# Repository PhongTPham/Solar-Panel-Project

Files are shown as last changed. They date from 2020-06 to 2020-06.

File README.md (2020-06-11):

# Introduction
This Solar Panel Project is a class project for a Power Electronics class. The aim was to build a device related to power that can be used for personal use, is relatively inexpensive and simple to assemble.

## [Link to the hardware](https://github.com/PhongTPham/Solar-Panel-Project/wiki/Main-Page#hardware)

This is what the completed circuit looks like:
solarPanelProject

## [Link to the Testing](https://github.com/PhongTPham/Solar-Panel-Project/wiki/Main-Page#testing)

# Current Status of this project:
At the moment this project doesn't quite work. When I was soldering parts onto the PCB something happened that fried my buck booster IC and as a result the entire section after the SPDT switch is rendered unusable since it feeds directly to the buck booster. If I connect my battery straight to the USB port and plug in a charger than it works just fine, but that defeats the purpose of the project.

## [Link to Future Considerations](https://github.com/PhongTPham/Solar-Panel-Project/wiki/Main-Page#future-considerations)

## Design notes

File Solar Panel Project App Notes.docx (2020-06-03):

Phong Pham

ENGR460

Stepping Stone

Application Notes

4/13/20

2.5W 5V/500mA Solar Panel

Acquired

A cheap 2.5W solar array

1N4007-TP Diode

https://www.digikey.com/product-detail/en/micro-commercial-co/1N4007-TP/1N4007-TPMSCT-ND/773694

https://www.mccsemi.com/pdf/Products/1N4001-1N4007(DO-41).pdf

High voltage, high current rated diode. Reverse voltage protection with rating of 1000V. Will prevent large

LM3658SD/NOPB Battery Charger

https://www.digikey.com/product-detail/en/texas-instruments/LM3658SD-NOPB/LM3658SD-NOPBCT-ND/808013

http://www.ti.com/lit/ds/symlink/lm3658.pdf

Lithium battery charger with charge current of 1A and battery pack voltage of 4.2 to 6V. Can safely charge a Li battery from USB power source.

PRT-13851 3.7V Lithium Battery

https://www.digikey.com/product-detail/en/sparkfun-electronics/PRT-13851/1568-1493-ND/6605199

https://cdn.sparkfun.com/datasheets/Prototyping/spe-00-502535-400mah-en-1.0ver.pdf

Will charge this from the solar panel for the USB output.

SN74LVC1G3157DBVR SPDT Switch

https://www.digikey.com/product-detail/en/texas-instruments/SN74LVC1G3157DBVR/296-14908-1-ND/562548

http://www.ti.com/general/docs/suppproductinfo.tsp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

Will make it so the device only charges battery when the solar panel is charging.

Buck Boost Voltage Regulator: RT4812

https://www.digikey.com/product-detail/en/richtek-usa-inc/RT4812GJ8F/1028-1512-1-ND/5640521

https://www.richtek.com/assets/product_file/RT4812/DS4812-07.pdf

Will boost battery 3.7V dc to 5V dc for USB output. Features 96% efficiency, output over voltage protection, and adjustable output voltage from 1.8V to 5.5V. Seems pretty good for this project.

Wireless Charger: Samsung 5V/2A wireless charger

Acquired. Is inefficient but that’s not why I’m choosing the wireless charger anyway.

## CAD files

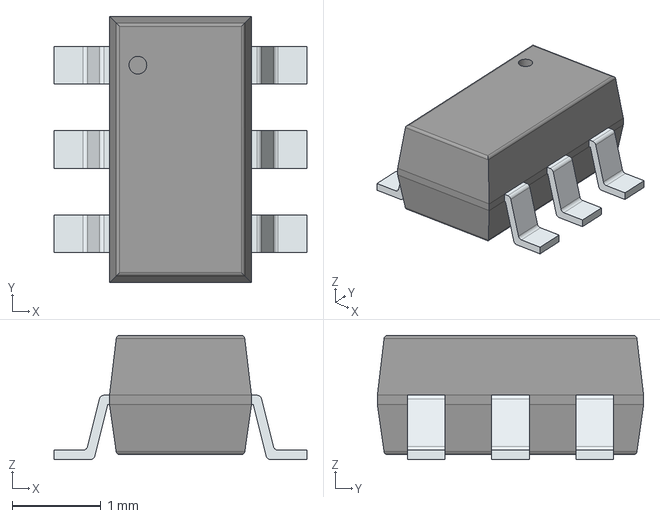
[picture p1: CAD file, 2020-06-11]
Kicad Lib/LIB_DMG6968UDM-7/DMG6968UDM-7/3D/DMG6968UDM-7.stp
2.85 x 3.00 x 1.40 mm
PinsArrayLR

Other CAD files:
Kicad Lib/LIB_DMG6968UDM-7/DMG6968UDM-7/3D/DMG6968UDM-7.stl
Kicad Lib/LIB_DMG6968UDM-7/DMG6968UDM-7/Allegro/sot95p285x140-6n.psm
Kicad Lib/LIB_DMG6968UDM-7/DMG6968UDM-7/DEHDL/dmg6968udm_7/chips/chips.prt

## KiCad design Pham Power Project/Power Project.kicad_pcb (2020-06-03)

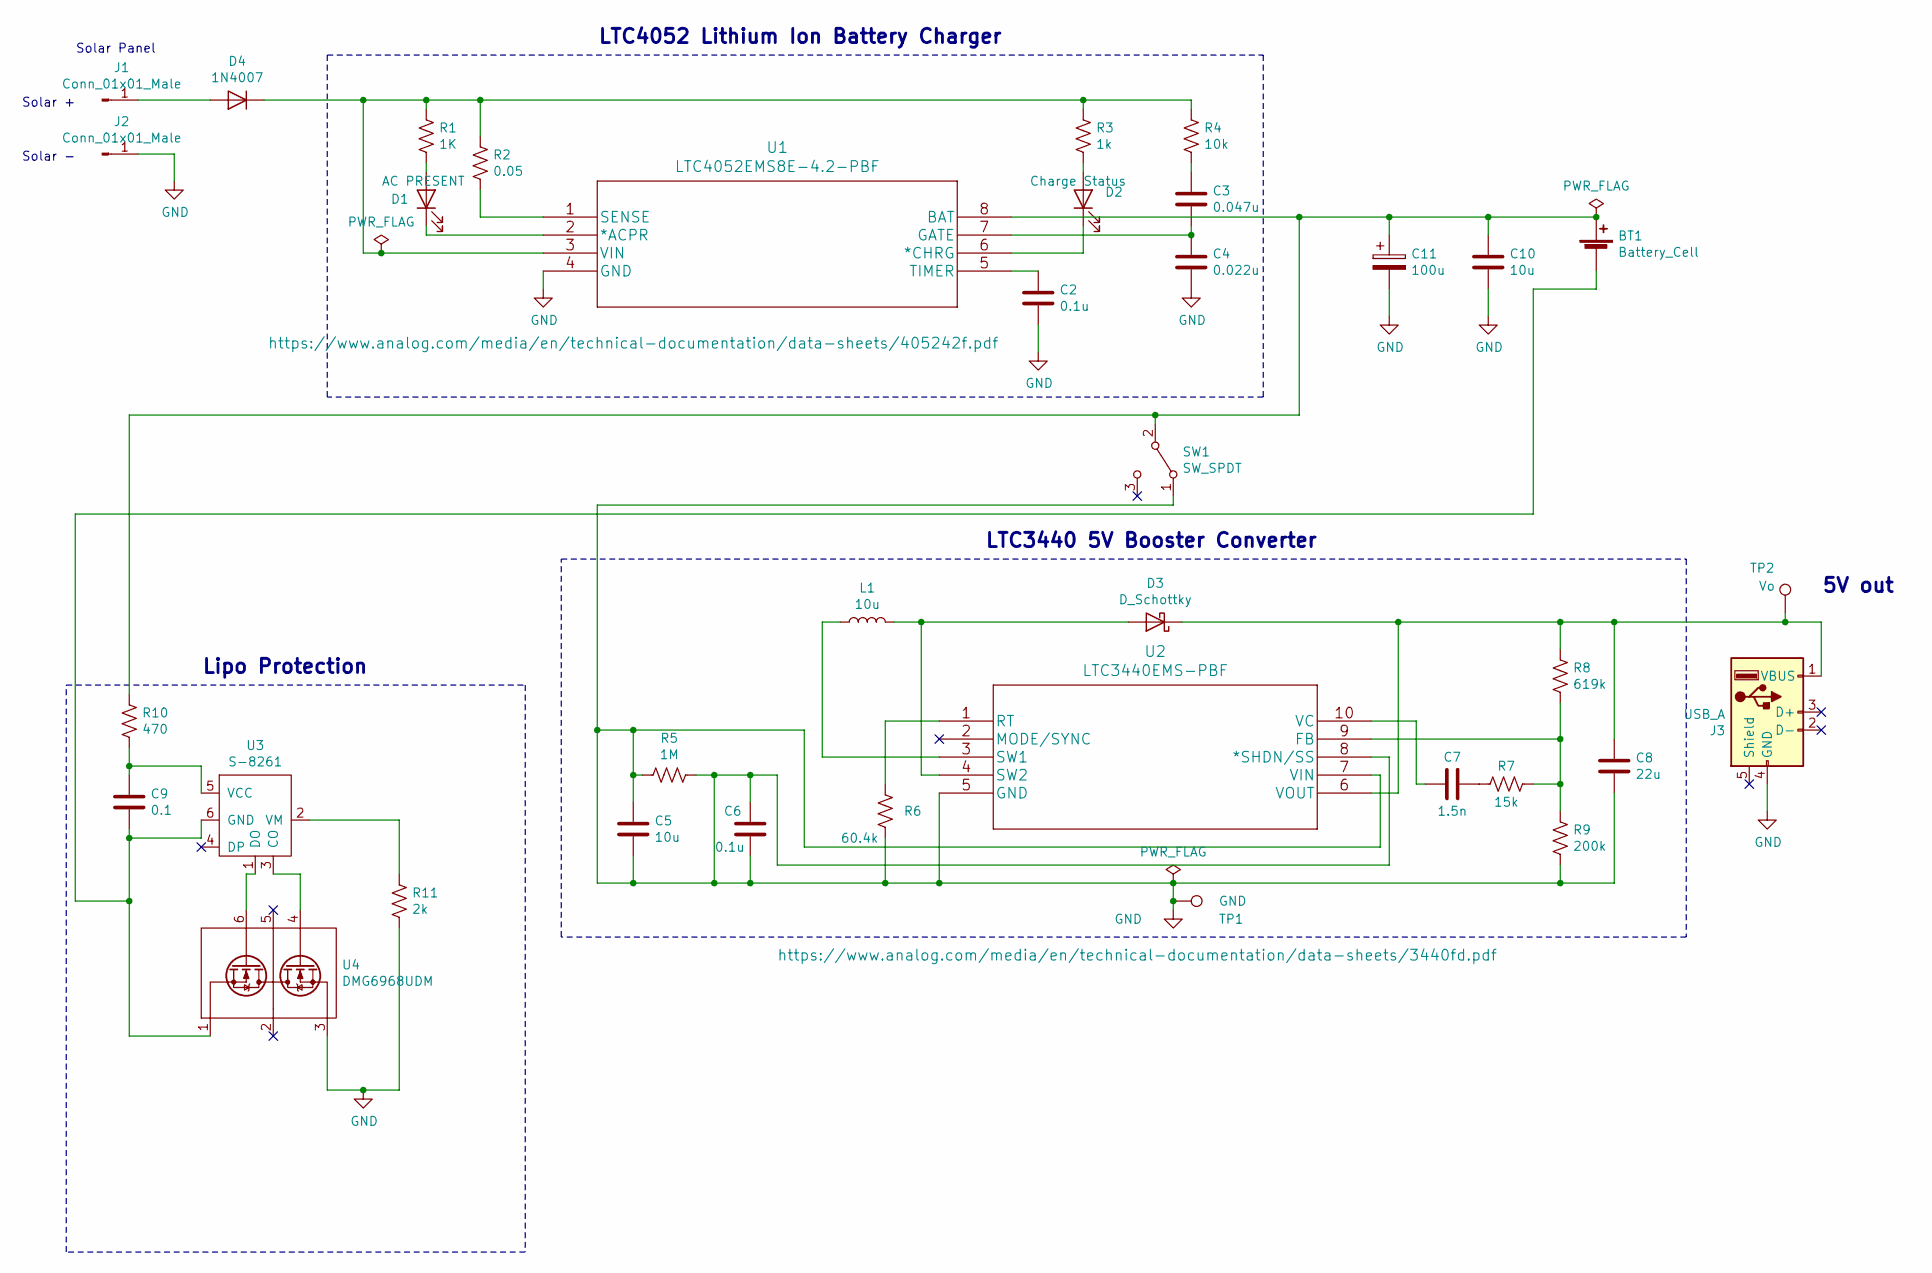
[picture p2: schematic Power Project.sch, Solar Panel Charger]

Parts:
BT1: Battery_Cell; BatteryHolder_MPD_BH-18650-PC2
C2, C6: 0.1u; C_0805_2012Metric
C3: 0.047u; C_0805_2012Metric
C4: 0.022u; C_0805_2012Metric
C5, C10: 10u; C_0805_2012Metric
C7: 1.5n; C_0805_2012Metric
C8: 22u; C_0805_2012Metric
C9: 0.1; C_0805_2012Metric
C11: 100u; CP_Elec_6.3x5.4_Nichicon
D1: AC PRESENT; LED_0805_2012Metric
D2: Charge Status; LED_0805_2012Metric
D3: D_Schottky; D_SMC
D4: 1N4007; D_DO-41_SOD81_P10.16mm_Horizontal
J1, J2: Conn_01x01_Male; SolderWirePad_1x01_Drill0.8mm
J3: USB_A; USB_A_CNCTech_1001-011-01101_Horizontal
L1: 10u; L_0805_2012Metric
R1: 1K; R_0805_2012Metric
R2: 0.05; R_0805_2012Metric
R3: 1k; R_0805_2012Metric
R4: 10k; R_0805_2012Metric
R5: 1M; R_0805_2012Metric
R6: 60.4k; R_0805_2012Metric
R7: 15k; R_0805_2012Metric
R8: 619k; R_0805_2012Metric
R9: 200k; R_0805_2012Metric
R10: 470; R_0805_2012Metric
R11: 2k; R_0805_2012Metric
SW1: SW_SPDT; SW_SPDT_PCM12
TP1: GND; TestPoint_Plated_Hole_D2.0mm
TP2: Vo; TestPoint_Plated_Hole_D2.0mm
U1: LTC4052EMS8E-4.2-PBF
U2: LTC3440EMS-PBF
U3: S-8261; SOT-23-6
U4: DMG6968UDM; SOT-23-6

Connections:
GND: C2.2, C4.2, C5.1, C5.2, C6.1, C6.2, C8.2, C10.2, C11.2, J2.1, J3.4 (GND), R5.1, R5.2, R6.2, R9.2, R11.2, SW1.1 (A), TP1.1, U1.4 (GND), U2.5 (GND), U2.7 (VIN), U2.8 (*SHDN/SS), U4.3
unnamed: BT1.1 (+), C10.1, C11.1, R10.1, SW1.2 (B), U1.8 (BAT)
unnamed: BT1.2 (-), C9.2, U3.6 (GND), U4.1
unnamed: C2.1, U1.5 (TIMER)
unnamed: C3.1, R4.2
unnamed: C3.2, C4.1, U1.7 (GATE)
unnamed: C7.1, R7.2
unnamed: C7.2, U2.10 (VC)
unnamed: C8.1, D3.1 (K), J3.1 (VBUS), R8.1, TP2.1, U2.6 (VOUT)
unnamed: C9.1, R10.2, U3.5 (VCC)
unnamed: D1.1 (K), U1.2 (*ACPR)
unnamed: D1.2 (A), R1.2
unnamed: D2.1 (K), U1.6 (*CHRG)
unnamed: D2.2 (A), R3.2
unnamed: D3.2 (A), L1.2, U2.4 (SW2)
unnamed: D4.1 (K), R1.1, R2.1, R3.1, R4.1, U1.3 (VIN)
unnamed: D4.2 (A), J1.1
unnamed: L1.1, U2.3 (SW1)
unnamed: R2.2, U1.1 (SENSE)
unnamed: R6.1, U2.1 (RT)
unnamed: R7.1, R8.2, R9.1, U2.9 (FB)
unnamed: R11.1, U3.2 (VM)
unnamed: U3.1 (DO), U4.6
unnamed: U3.3 (CO), U4.4

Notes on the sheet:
Solar Panel
Solar +
Solar -
5V out
LTC4052 Lithium Ion Battery Charger
Lipo Protection
LTC3440 5V Booster Converter

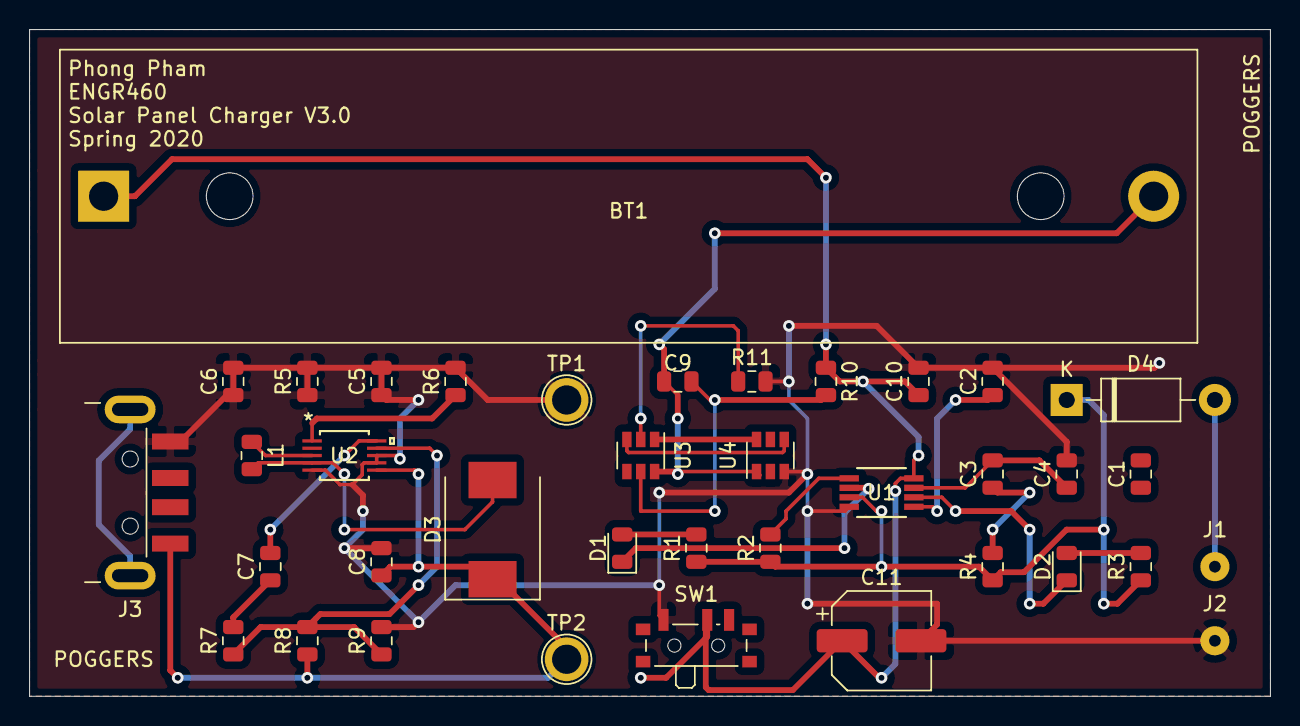
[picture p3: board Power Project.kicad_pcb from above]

Board: 2 copper layers, 85.1 x 45.7 mm, 38 parts (0 on the bottom side), 24 nets.

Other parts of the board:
C1: 1uF; C_0805_2012Metric

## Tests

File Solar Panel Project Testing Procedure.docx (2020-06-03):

Phong Pham

ENGR460

Power Project Stepping Stone 4

May 18, 2020

Project Overview

I will be constructing a wireless charger that uses a 5V Solar Panel and 5V Samsung Wireless charger to charge a lithium-ion battery. The charger will have a 5V booster converter and lip protection built alongside it. These are the 3 main components of the project circuit board:

Lithium Ion Battery Charger

LTC4052EMS8E

The LTC4052 takes the voltage from the solar panel and charges Lipo battery

https://www.analog.com/media/en/technical-documentation/data-sheets/405242f.pdf

5V Booster Converter

LTC3440EMS

LTC3440 converts the 3.7 voltage output of the lipo to 5V for the USB charger.

https://www.analog.com/media/en/technical-documentation/data-sheets/3440fd.pdf

Lipo Protection

S-8261 and DMG6968UDM

The two ICs add additional protection to conditions like overvolt, undervoltage, overcharge and overcurrent.

https://www.ablic.com/en/doc/datasheet/battery_protection/S8261_E.pdf

https://www.diodes.com/assets/Datasheets/ds31758.pdf

Pre-Planning

- Fill out the Academic Exception Form to campus so I can use the project lab to build my board
- Prepare workspace to test board when it is finished being assembled

Initial Procedure

- Confirm all parts have been delivered
- Examine PCB for any faults or defects from shipping or manufacture

Assembly of PCB

- Apply solder paste with stencil
- Pick and place the SMD parts
- Bake the PCB using the project labs oven
- Check ICs after baking in case of shorts or any potential unflowed solder
- Hand Solder through-hole parts
- Check for shorts using multimeter

Testing of the Battery Charger

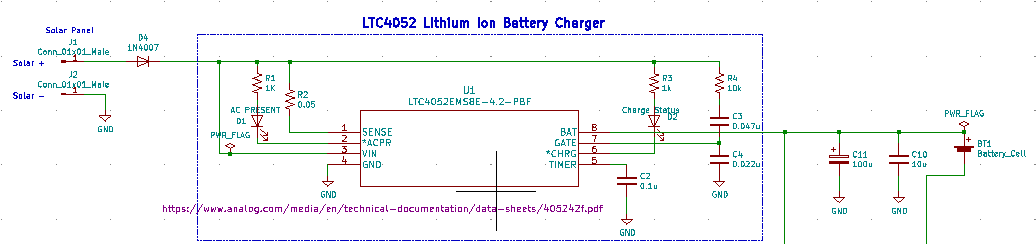
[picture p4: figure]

- Test that the solar panel is able to the charge the battery:
  - D1 and D2 LEDs will indicate that it’s charging
  - D1 (AC present) shows that power is present
  - D2 shows that charging is indeed taking place
- Test the output current: making sure it doesn’t exceed 750mA
- Test the thermal protection that is on the IC: circuit will turn off if the temperature exceeds 140 degrees Celsius.

Testing of the Booster Converter

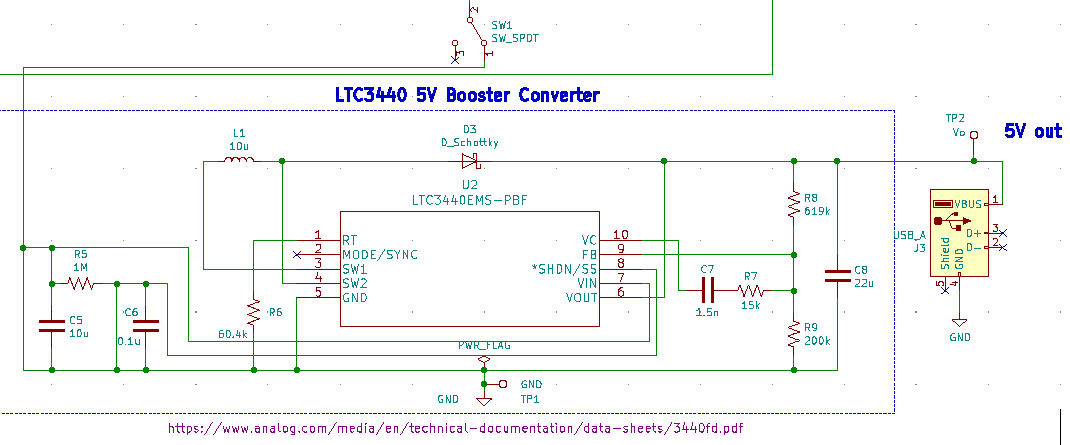
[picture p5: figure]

- We want to verify the 5V output via testing point 2 (TP2)
- Test efficiency using the waveform graphs from Linear Technology

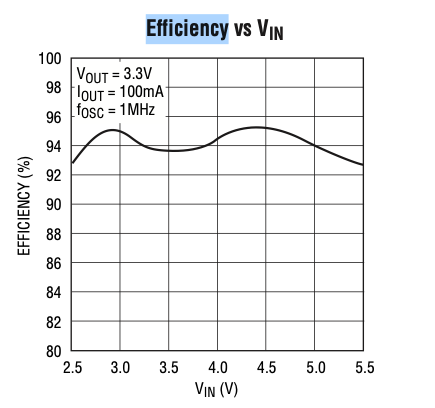
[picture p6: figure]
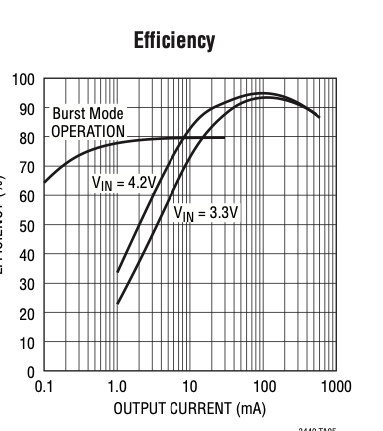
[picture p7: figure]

Testing of the Lipo Protection

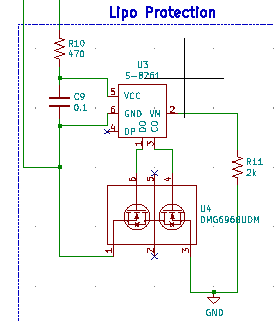
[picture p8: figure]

- Test for undervoltage as the charging IC comes with overcurrent protection
  - when battery voltage drops below 2.8V it should activate
- While there are no test points for DO and CO, we should test those spots for the power MOSFET bias.

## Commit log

2020-06-03 Added KICAD files for Solar Panel Project
    [Power Project-B_Cu.gbr, Power Project-B_Mask.gbr, Power Project-B_Paste.gbr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]
2020-06-11 BOM for the initial PCB design
2020-06-11 Kicad Libraries
    added libraries for kicad parts
    [DMG6968UDM-7.stl, DMG6968UDM-7.stp, EDI2CAP.CFG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]

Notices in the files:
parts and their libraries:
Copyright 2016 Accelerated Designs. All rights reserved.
